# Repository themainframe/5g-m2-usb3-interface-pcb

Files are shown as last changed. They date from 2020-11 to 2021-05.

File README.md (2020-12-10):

# 5G M.2 USB3 Interface Board

I’ve been experimenting with 5G cellular modules recently, and found that many of the M.2 break-out boards that run on just USB power (mostly designed for 4G modules) can’t supply the required current at the peaks during transmission. I decided to design my own in KiCad with dual-power input, Nano-SIM slot, and USB 3 to support the required data rates for 5G. 

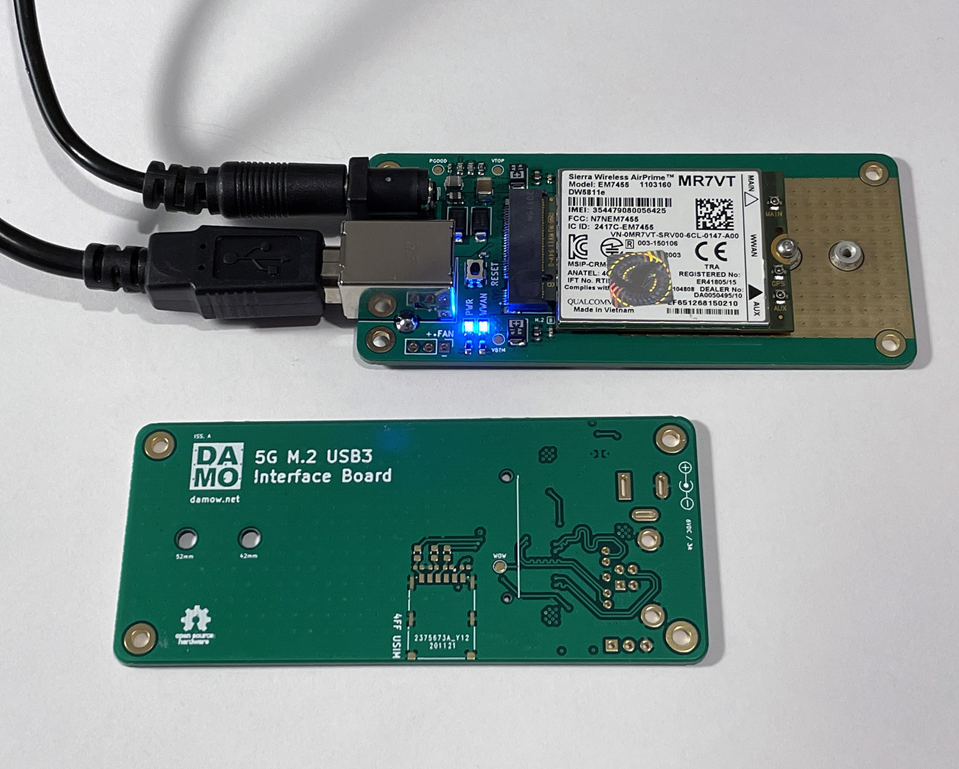
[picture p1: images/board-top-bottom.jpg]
Board with an old 4G module installed for testing. No, I don't care about the IMEI number...


I'm using mine with a Quectel [RM500Q-GL](https://www.quectel.com/product/rm500q.htm) 5G module that I've previously [blogged about](https://damow.net/5g-home-broadband/). The design very much obeys the appnote recommendations for the RM500Q-GL module so use with that one especially should work fine.

## Features

* Compact size, 90mm x 40mm board size; with 82mm x 32mm spaced M2.5 mounting holes
* USB 3.0 SuperSpeed for high 5G data rates
* Dual-power input.
    * USB 3.0 B (not recommended for heavy data use, but fine for lower-end modules)
    * 5-9V DC 5.5mm barrel jack (centre-positive)
* Fits both 52mm and 42mm M.2 B-Key modules
* Single 4FF Nano-SIM USIM slot
* Module reset button
* Module WWAN LED
* Power LED
* 5V 3-pin fan header

## Stackup & BOM

4 layers. Standard FR4. ENIG recommended for easier soldering of the fine-pitch parts (M.2 connector & TPS82130SILR DC-DC converter)

BOM can be found in the `bom/` directory. Currency is GBP. Total build cost (excluding non-special caps & resistors) is ~£15 in 10qty.

## Questions?

Open an issue or drop me an email - `me@` my blog domain.

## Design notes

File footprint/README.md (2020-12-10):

# Third Party Footprint Assets

Some of these assets are property of their respective owners.

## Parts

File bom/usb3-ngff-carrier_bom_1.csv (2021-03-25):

Component | Description | Part | References | Value | Footprint | Quantity Per PCB | Datasheet | SKU | Vendor | Int @ 10 | MPN | Mfr | Note
1 | Unpolarized capacitor | C | C8 C13 | 10pF | C_0402_1005Metric | 2 | ~ | 963-TMK042CG100DD-W | Mouser | 0.031 | TMK042CG100DD-W | Taiyo-Yuden
2 | Unpolarized capacitor | C | C7 C12 C14 C17 C18 C19 | 33pF | C_0402_1005Metric | 6 | ~ | 81-GRM0225C1H330JA2L | Mouser | 0.038 | GRM0225C1H330JA02L | MuRata Electronics
3 | Unpolarized capacitor | C | C2 | 430pF | C_0402_1005Metric | 1 | ~ | 80-C0402C431J5GACTU | Mouser | 0.206 | C0402C431J5GACTU | KEMET
4 | Unpolarized capacitor | C | C6 C11 C16 | 100nF | C_0402_1005Metric | 3 | ~ | 80-C0402C104K9RAUTO | Mouser | 0.039 | C0402C104K9RACAUTO | KEMET
5 | Unpolarized capacitor | C | C5 C10 | 1uF | C_0603_1608Metric | 2 | ~ | 80-C0603C105K9R7411 | Mouser | 0.077 | C0603C105K9RAC7411 | KEMET
6 | Unpolarized capacitor | C | C1 | 10uF | C_0805_2012Metric | 1 | ~ | 963-JMF212AB7106KGHT | Mouser | 0.106 | JMF212AB7106KGHT | Taiyo-Yuden
7 | Unpolarized capacitor | C | C3 | 22uF | C_1210_3225Metric | 1 | ~ | 963-TMK325B7226MMHP | Mouser | 0.386 | TMK325B7226MMHP | Taiyo-Yuden
8 | Polarized capacitor | CP | C4 C9 | 100uF | CP_EIA-3528-21_Kemet-B | 2 | ~ | 667-6TPE100MZB | Mouser | 0.703 | 6TPE100MZB | Panasonic | Tantalum
9 | Light emitting diode | LED | D3 D4 | LED | LED_0805_2012Metric | 2 | ~ | 604-APTD2012LQBCD | Mouser | 0.284 | APTD2012LQBC/D | Kingbright | WWAN VCCON
10 | 40V 3A Schottky Barrier Rectifier Diode, SMA(DO-214AC) | MBRA340 | D1 D2 | MBRA340 | D_SMA | 2 | https://www.onsemi.com/pub/Collateral/MBRA340T3-D.PDF | 863-MBRA340T3G | Mouser | 0.262 | MBRA340T3G | ON Semiconductor
11 | Mounting Hole without connection | MountingHole | H1 H2 | M2 Threaded Insert | 9774015243RStandoff | 2 | https://www.mouser.co.uk/datasheet/2/445/9774015243R-1728818.pdf | 710-9774015243R | Mouser | 0.785 | 9774015243R | Wurth
12 |  | 2199119-3 | J2 | 2199119-3 | TE_2199119-3 | 1 |  | 571-2199119-3 | Mouser | 0.831 | 2199119-3 | TE Connectivity | NGFF (M.2 B-Key)
13 |  | 692221030100 | J1 | 692221030100 | Wurth-692221030100-0-0-MFG | 1 | https://katalog.we-online.de/em/datasheet/692221030100.pdf | 710-692221030100 | Mouser | 2.79 | 692221030100 | Wurth
14 |  | 693043020611 | J4 | 693043020611 | Wurth-693043020611-MFG | 1 | https://www.we-online.com/catalog/datasheet/693043020611.pdf | 710-693043020611 | Mouser | 1.25 | 693043020611 | Wurth
15 | Generic connector, single row, 01x03, script generated (kicad-library-utils/schlib/autogen/connector/) | Conn_01x03_Male | J5 | Conn_01x03_Male | PinHeader_1x03_P2.54mm_Vertical | 1 | ~
16 | DC Barrel Jack with a mounting pin | Barrel_Jack_MountingPin | J3 | Jack-DC | BarrelJack_Wuerth_6941xx301002 | 1 | ~ | 710-694106301002 | Mouser | 0.74 | 694106301002 | Wurth
17 | Resistor | R | R6 R7 R8 | 22R | R_0603_1608Metric | 3 | ~
18 | Resistor | R | R1 R4 R9 | 330R | R_0603_1608Metric | 3 | ~
19 | Resistor | R | R2 R5 | 100k | R_0603_1608Metric | 2 | ~
20 | Resistor | R | R3 | 374k | R_0603_1608Metric | 1 | ~
21 |  | KMR221GLFS | SW1 | KMR221GLFS | CK-KMR221GLFS-MFG | 1 | https://www.ckswitches.com/media/1479/kmr2.pdf | 611-KMR221G-LFS | Mouser | 0.411 | KMR221GLFS | C&K
22 |  | TPS82130SILR | U1 | TPS82130SILR | Texas_Instruments-SIL0008D-0-0-0 | 1 | http://www.ti.com/lit/ds/symlink/tps82130.pdf | 595-TPS82130SILR | Mouser | 2.72 | TPS82130SILR | Texas Instruments

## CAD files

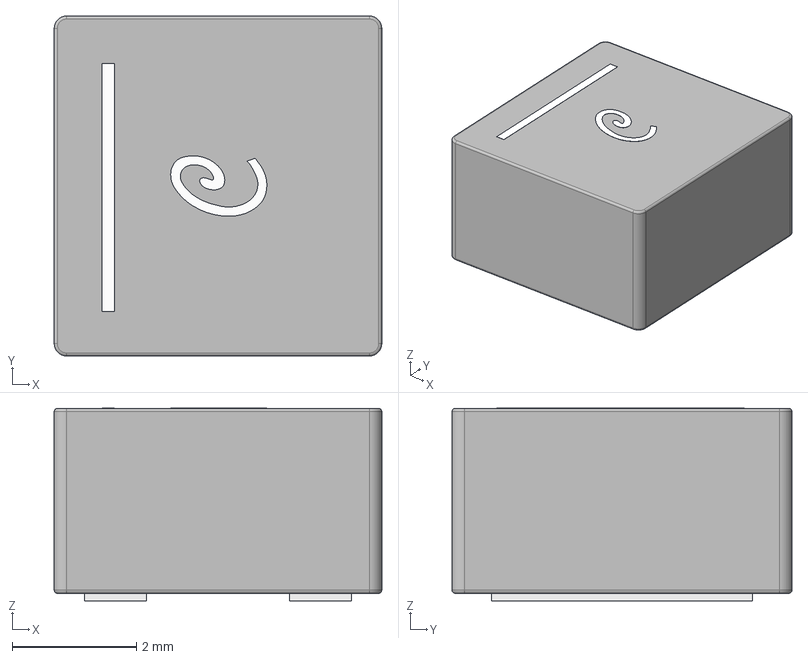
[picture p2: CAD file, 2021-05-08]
3d/Coilcraft_-_XAL5030-222MEB.step
5.28 x 5.48 x 3.10 mm
terminals
logo

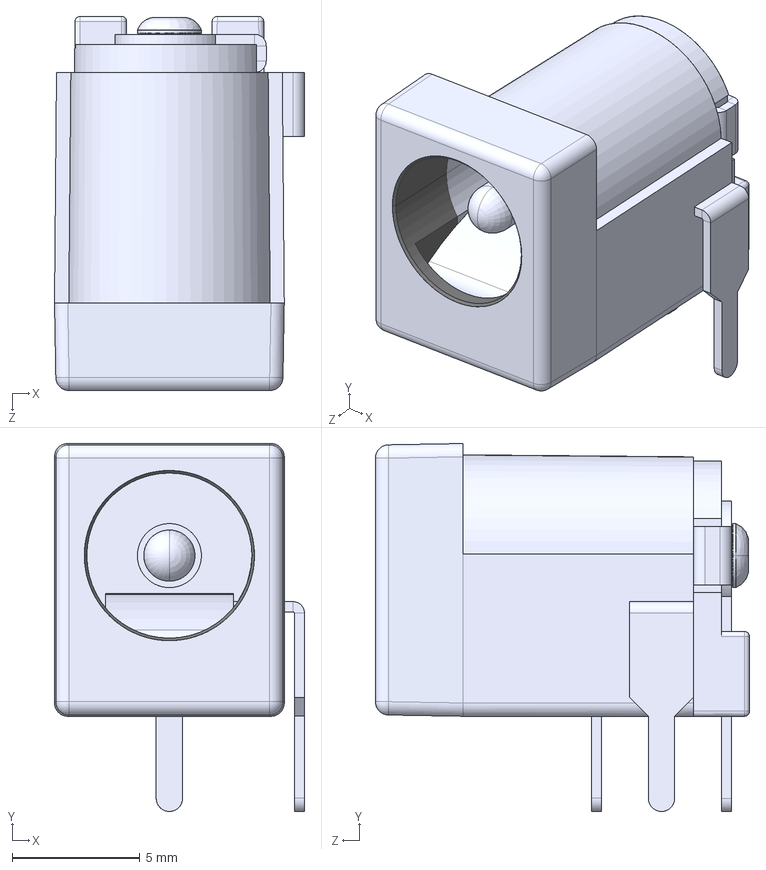
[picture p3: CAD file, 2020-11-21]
3d/DC Power Jack 5.5mm x 2.1mm.IGS
9.77 x 14.4 x 14.6 mm

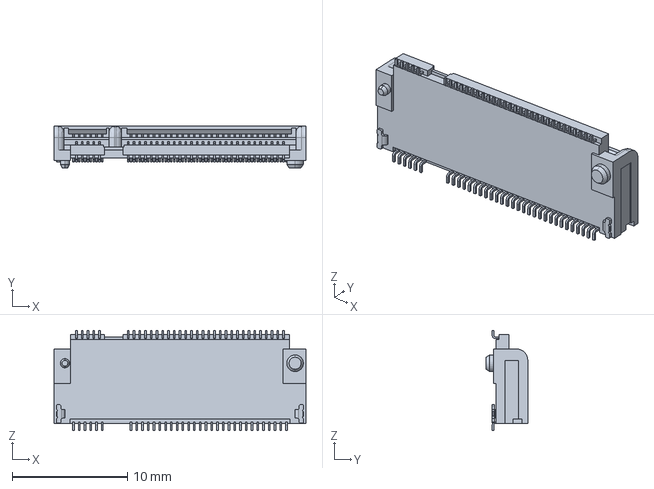
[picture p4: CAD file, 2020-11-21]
3d/c-2199119-3-c-3d.stp
21.9 x 3.62 x 8.70 mm

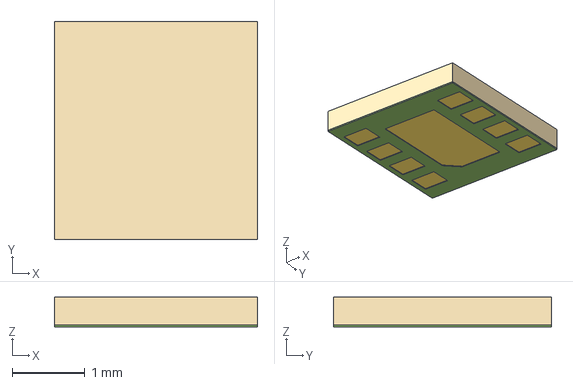
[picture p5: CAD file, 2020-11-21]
3d/Texas_Instruments_-_TPS82130SILR.step
2.80 x 3.00 x 0.41 mm

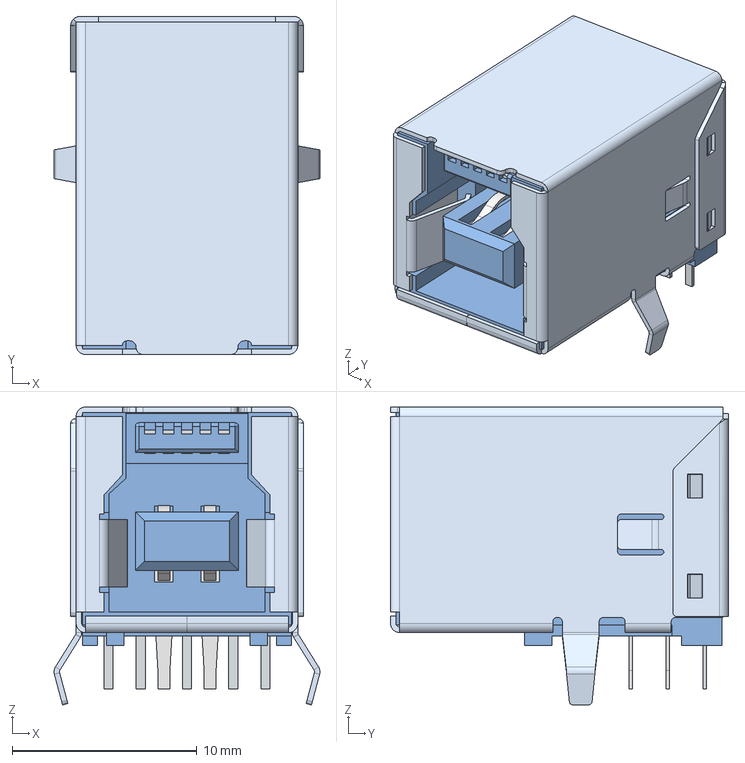
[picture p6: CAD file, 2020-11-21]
3d/Wurth_-_692221030100.step
14.4 x 18.3 x 16.1 mm

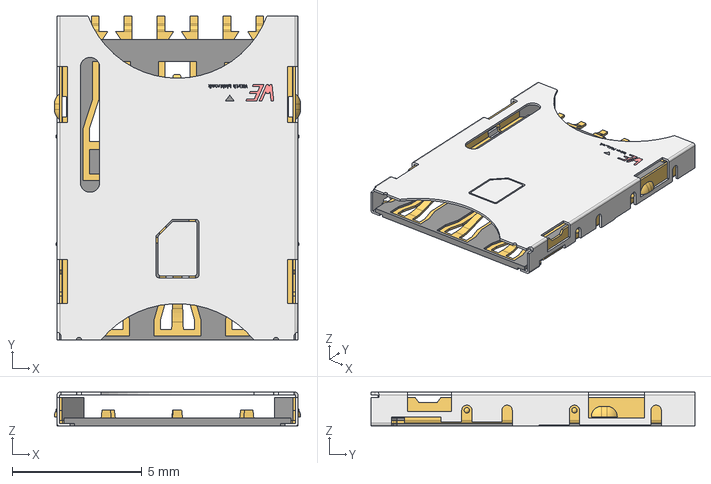
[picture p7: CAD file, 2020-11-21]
3d/Wurth_-_693043020611.step
9.50 x 12.5 x 1.30 mm

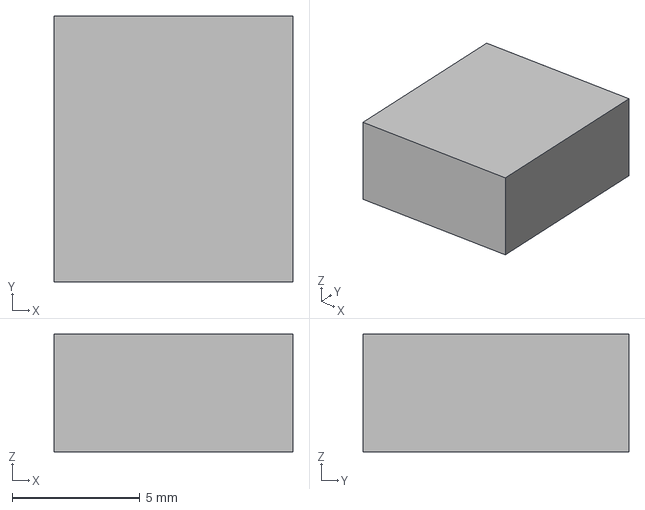
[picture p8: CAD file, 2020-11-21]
3d/STMicroelectronics_-_LD1085D2T33R.step
9.35 x 10.4 x 4.60 mm

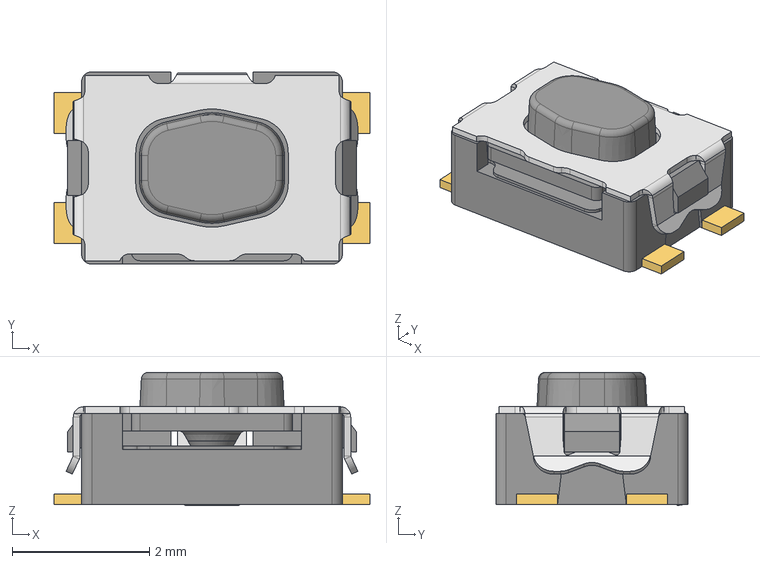
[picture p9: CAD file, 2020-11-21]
3d/C&K_-_KMR221GLFS.step
4.60 x 2.80 x 1.94 mm

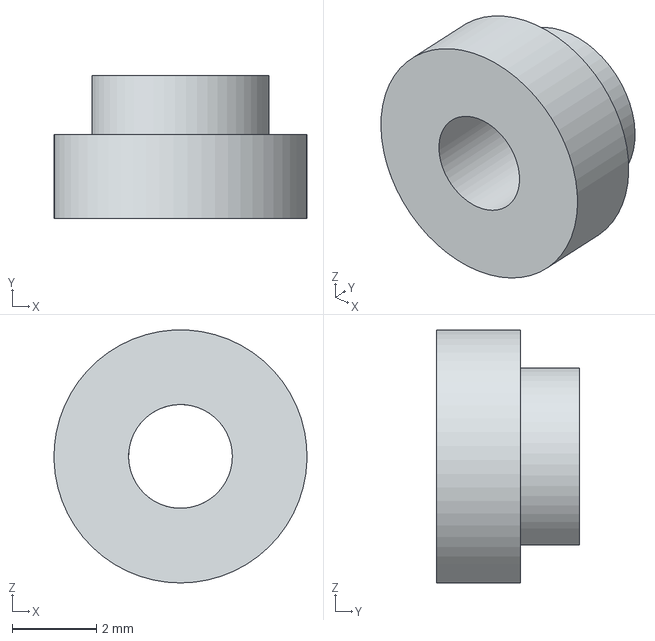
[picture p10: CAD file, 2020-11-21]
3d/9774020360R-Standoff.stp
6.00 x 3.40 x 6.00 mm

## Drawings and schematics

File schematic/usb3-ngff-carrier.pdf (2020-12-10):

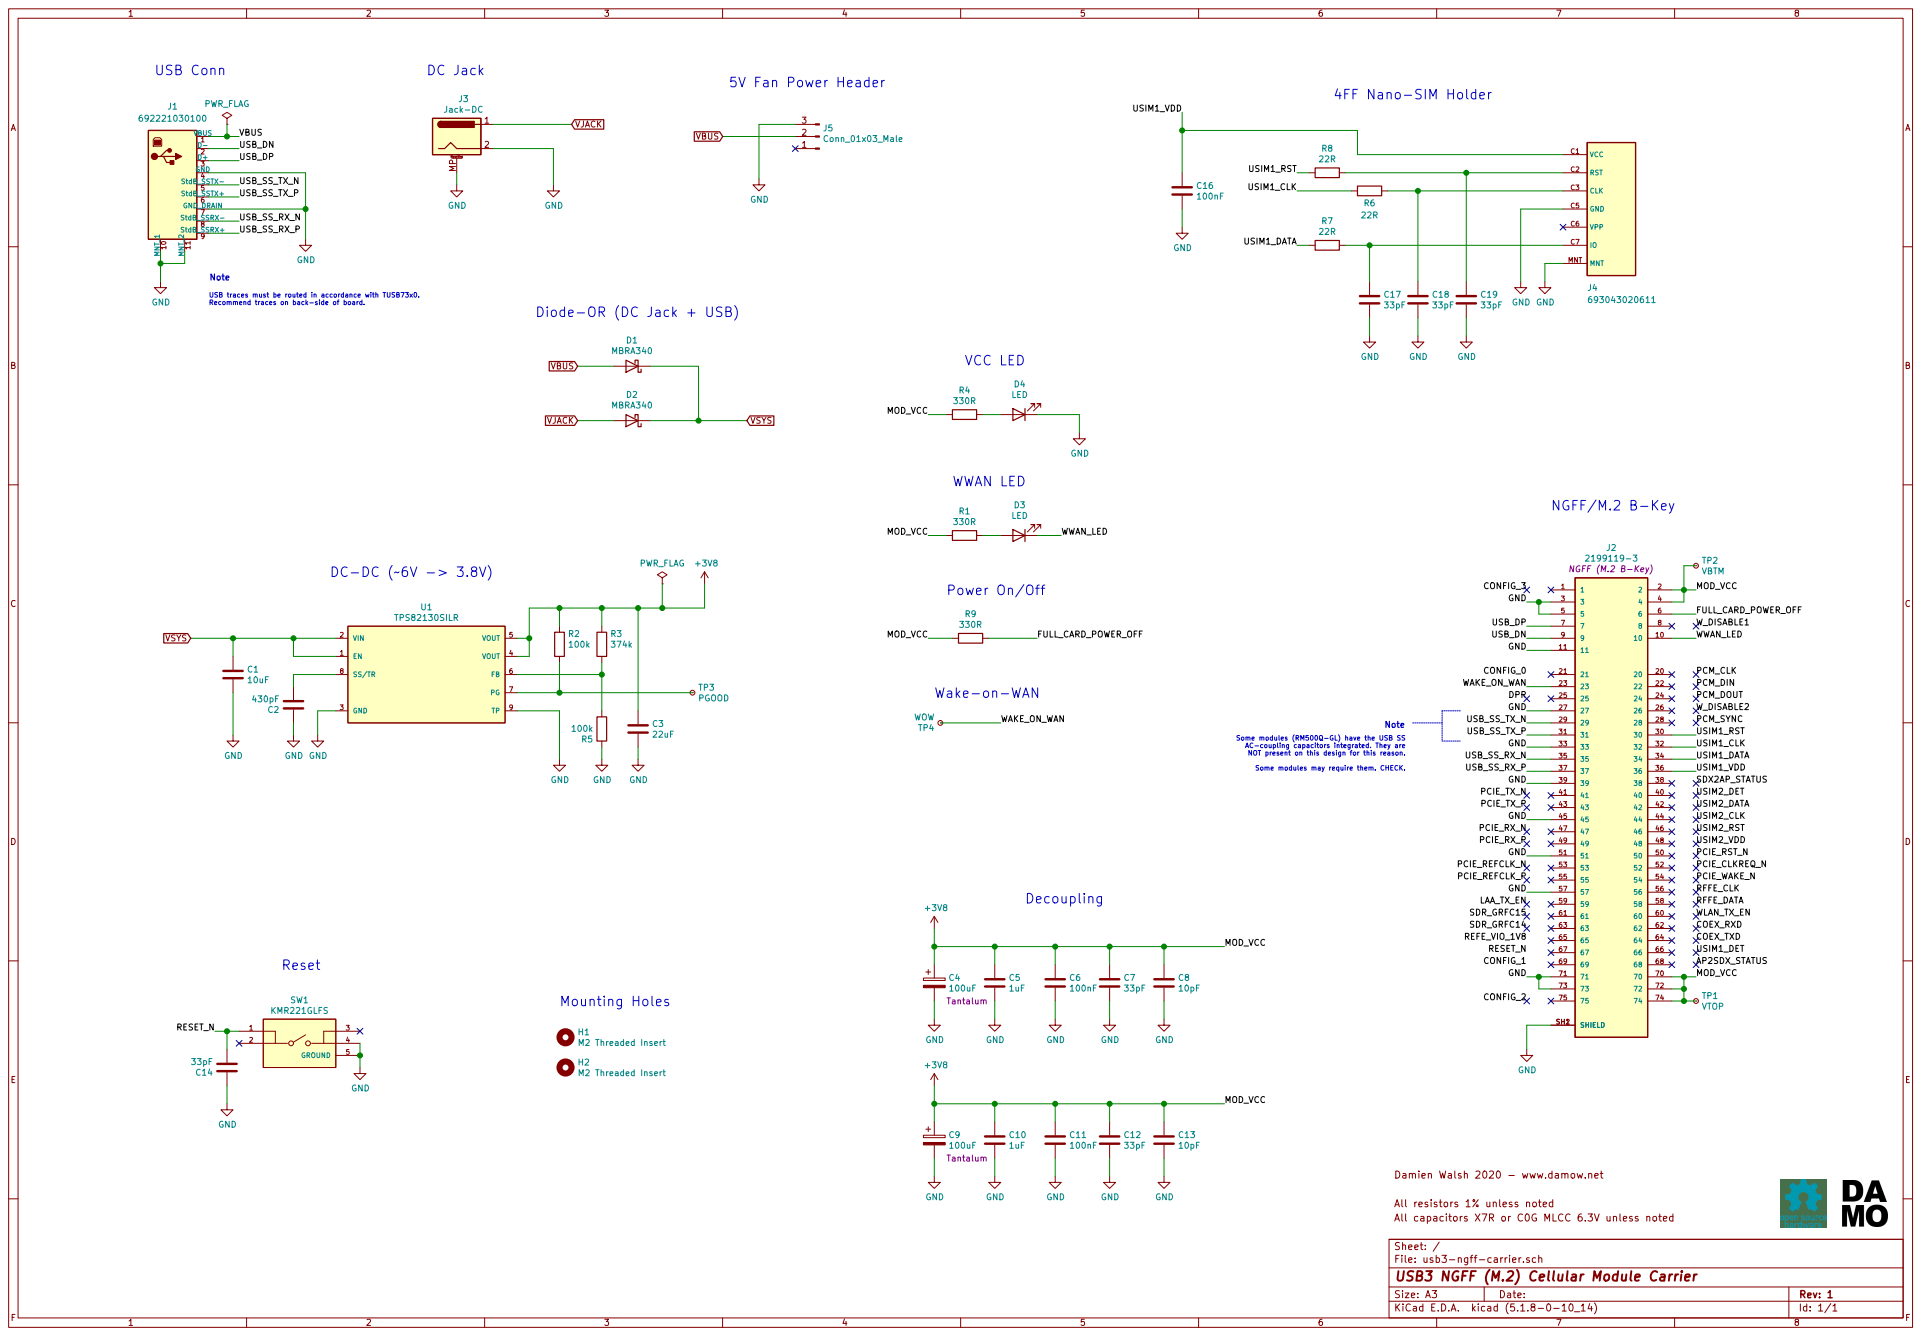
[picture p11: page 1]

SDR_GRFC14 SDR_GRFC15 Diode-OR (DC Jack + USB)

AC-coupling capacitors integrated. They are NOT present on this design for this reason. Some modules may require them. CHECK. Power On/Off

Some modules (RM500Q-GL) have the USB SS

H2M2 Threaded Insert H1M2 Threaded Insert GND

File: usb3-ngff-carrier.sch Sheet: / All capacitors X7R or C0G MLCC 6.3V unless noted All resistors 1% unless noted Damien Walsh 2020 - www.damow.net

Id: 1/1 USB3 NGFF (M.2) Cellular Module Carrier

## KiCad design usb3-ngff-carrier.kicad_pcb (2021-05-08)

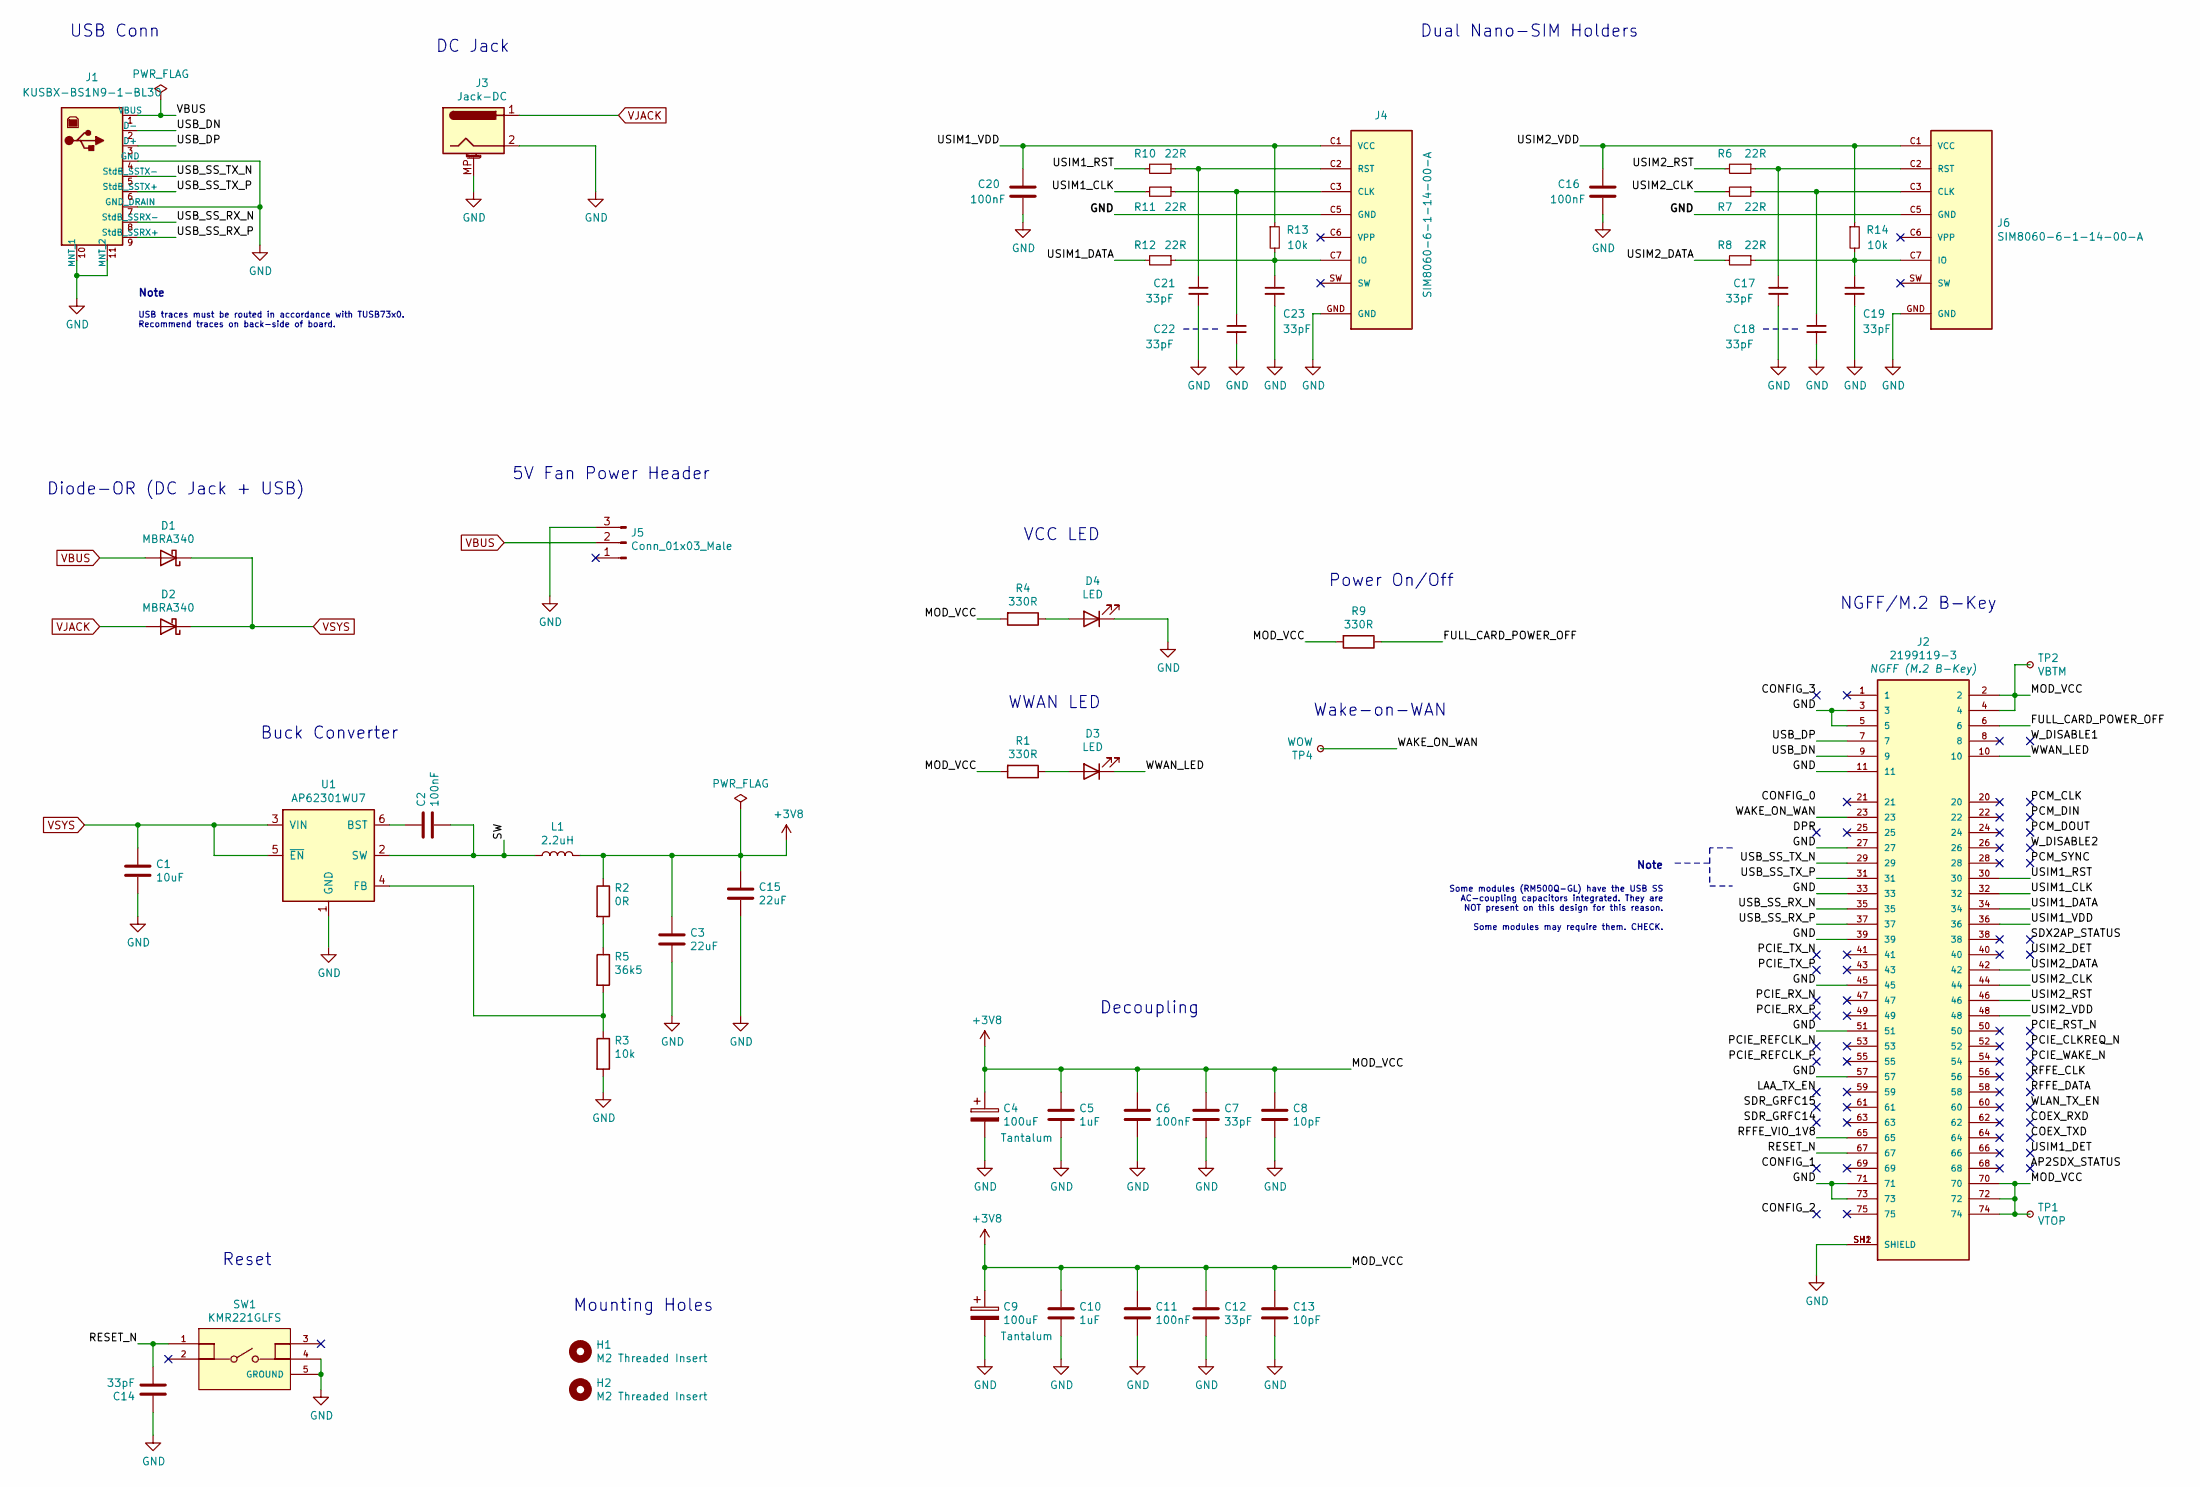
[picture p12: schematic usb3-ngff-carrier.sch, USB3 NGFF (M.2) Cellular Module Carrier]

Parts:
C1: 10uF; C_0805_2012Metric; MPN GRM21BR71A106KA73K
C2, C6, C11, C16, C20: 100nF; C_0603_1608Metric; MPN C0603C104K3RAC
C3, C15: 22uF; C_1210_3225Metric; MPN CL32B226MOJNNNE
C4, C9: 100uF; CP_EIA-3528-21_Kemet-B; MPN TCJB107M006R0040
C5, C10: 1uF; C_0603_1608Metric; MPN CGA3E1X7R1C105K080AC
C7, C12, C14, C17, C18, C19, C21, C22, C23: 33pF; C_0603_1608Metric; MPN 06035A330KAT2A
C8, C13: 10pF; C_0603_1608Metric; MPN 06035A100JAT4A
D1, D2: MBRA340; D_SMA; MPN MBRA340T3G
D3, D4: LED; LED_0805_2012Metric; MPN APTD2012LQBC/D
H1, H2: M2 Threaded Insert; 9774015243RStandoff; MPN 9774015243R
J1: KUSBX-BS1N9-1-BL30; Wurth-692221030100-0-0-MFG; MPN KUSBX-BS1N9-1-BL30
J2: 2199119-3; TE_2199119-3; MPN 2199119-3
J3: Jack-DC; BarrelJack_Wuerth_6941xx301002; MPN 694106301002
J4, J6: SIM8060-6-1-14-00-A; GCT_SIM8060-6-1-14-00-A; MPN SIM8060-6-1-14-00-A
J5: Conn_01x03_Male; PinHeader_1x03_P2.54mm_Vertical
L1: 2.2uH; L_Coilcraft_XAL5030; MPN XAL5030-222MEC
R1, R4, R9: 330R; R_0603_1608Metric
R2: 0R; R_0603_1608Metric
R3, R13, R14: 10k; R_0603_1608Metric
R5: 36k5; R_0603_1608Metric; MPN CRCW060336K5FKEA
R6, R7, R8, R10, R11, R12: 22R; R_0603_1608Metric
SW1: KMR221GLFS; CK-KMR221GLFS-MFG; MPN KMR221GLFS
TP1: VTOP; TestPoint_Pad_D1.5mm
TP2: VBTM; TestPoint_Pad_D1.5mm
TP4: WOW; TestPoint_Pad_D1.5mm
U1: AP62301WU7; TSOT-23-6; MPN AP62301WU-7

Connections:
+3V8: C3.1, C4.1, C5.1, C6.1, C7.1, C8.1, C9.1, C10.1, C11.1, C12.1, C13.1, C15.1, J2.2, J2.4, J2.70, J2.72, J2.74, L1.2, R1.2, R2.1, R4.2, R9.2, TP1.1, TP2.1
/FULL_CARD_POWER_OFF: J2.6, R9.1
/RESET_N: C14.2, J2.67, SW1.1
/RFFE_VIO_1V8: J2.65
/SW: C2.2, L1.1, U1.2 (SW)
/USB_DN: J1.2 (D-), J2.9
/USB_DP: J1.3 (D+), J2.7
/USB_SS_RX_N: J1.8 (StdB_SSRX-), J2.35
/USB_SS_RX_P: J1.9 (StdB_SSRX+), J2.37
/USB_SS_TX_N: J1.5 (StdB_SSTX-), J2.29
/USB_SS_TX_P: J1.6 (StdB_SSTX+), J2.31
/USIM1_CLK: J2.32, R11.2
/USIM1_DATA: J2.34, R12.2
/USIM1_RST: J2.30, R10.2
/USIM1_VDD: C20.1, J2.36, J4.C1 (VCC), R13.1
/USIM2_CLK: J2.44, R7.2
/USIM2_DATA: J2.42, R8.2
/USIM2_RST: J2.46, R6.2
/USIM2_VDD: C16.1, J2.48, J6.C1 (VCC), R14.1
/WAKE_ON_WAN: J2.23, TP4.1
/WWAN_LED: D3.1 (K), J2.10
GND: C1.2, C3.2, C4.2, C5.2, C6.2, C7.2, C8.2, C9.2, C10.2, C11.2, C12.2, C13.2, C14.1, C15.2, C16.2, C17.2, C18.2, C19.2, C20.2, C21.2, C22.2, C23.2, D4.1 (K), J1.4 (GND), J1.7 (GND_DRAIN), J1.10 (MNT_1), J1.11 (MNT_2), J2.3, J2.5, J2.11, J2.27, J2.33, J2.39, J2.45, J2.51, J2.57, J2.71, J2.73, J2.SH1 (SHIELD), J2.SH2 (SHIELD), J3.2, J3.MP (MountPin), J4.C5 (GND), J4.GND, J5.3, J6.C5 (GND), J6.GND, R3.2, SW1.4, SW1.5 (GROUND), U1.1 (GND)
unnamed: C2.1, U1.6 (BST)
unnamed: C17.1, J6.C2 (RST), R6.1
unnamed: C18.1, J6.C3 (CLK), R7.1
unnamed: C19.1, J6.C7 (IO), R8.1, R14.2
unnamed: C21.1, J4.C2 (RST), R10.1
unnamed: C22.1, J4.C3 (CLK), R11.1
unnamed: C23.1, J4.C7 (IO), R12.1, R13.2
unnamed: D3.2 (A), R1.1
unnamed: D4.2 (A), R4.1
unnamed: R2.2, R5.1
unnamed: R3.1, R5.2, U1.4 (FB)
VBUS: D1.2 (A), J1.1 (VBUS), J5.2
VJACK: D2.2 (A), J3.1
VSYS: C1.1, D1.1 (K), D2.1 (K), U1.3 (VIN), U1.5 (~EN)

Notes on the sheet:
Dual Nano-SIM Holders
VCC LED
WWAN LED
Reset
5V Fan Power Header
Diode-OR (DC Jack + USB)
USB Conn
DC Jack
Power On/Off
Decoupling
NGFF/M.2 B-Key
Wake-on-WAN
Mounting Holes
Note
Some modules (RM500Q-GL) have the USB SS AC-coupling capacitors integrated. They are NOT present on this design for this reason. Some modules may require them. CHECK.
USB traces must be routed in accordance with TUSB73x0. Recommend traces on back-side of board.
Buck Converter

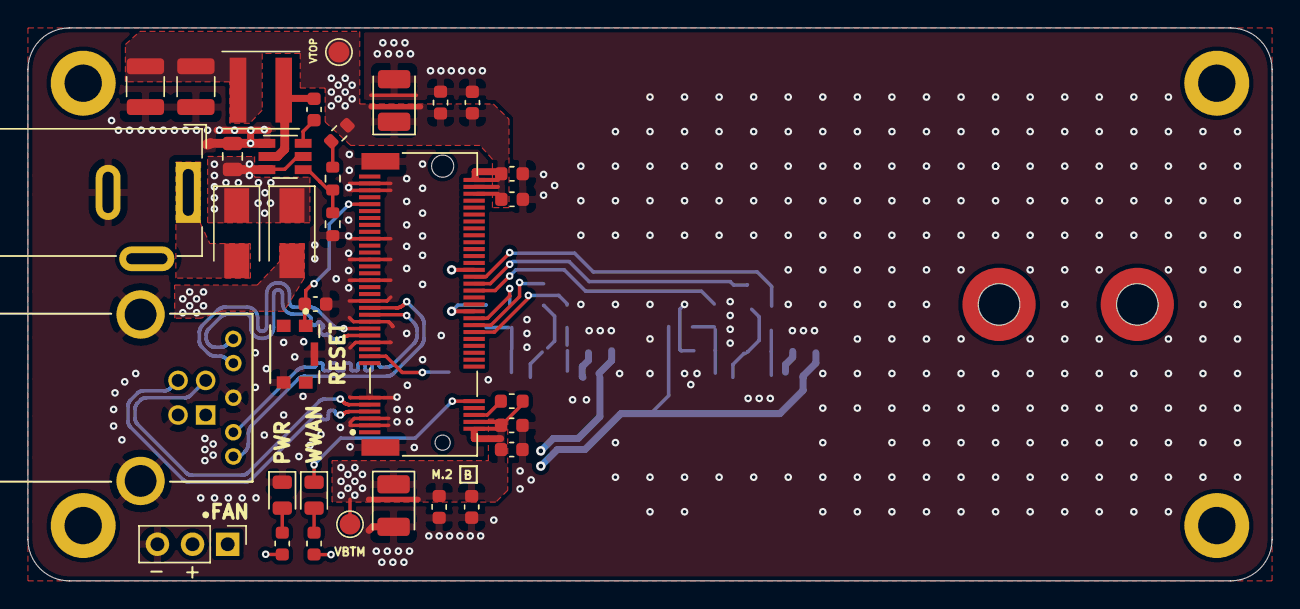
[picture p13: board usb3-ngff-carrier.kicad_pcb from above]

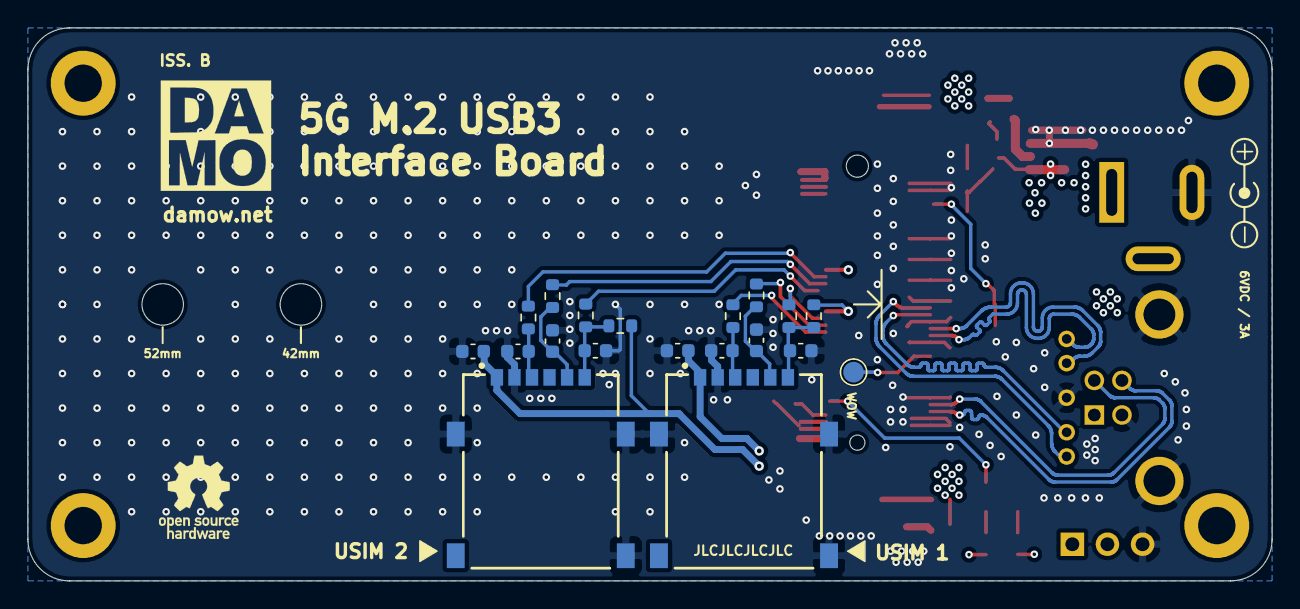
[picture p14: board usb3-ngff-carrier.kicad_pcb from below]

Board: 4 copper layers, 90.0 x 40.0 mm, 55 parts (19 on the bottom side), 35 nets.

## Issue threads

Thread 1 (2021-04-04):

Very nice design, but lacks sufficient cooling area for 5G

mlinuxguy, 2021-04-04:
I've been playing with 5G modems for my home internet and have various USB 3.0 M.2 sleds that I've tried.  Your design is one of the better ones I've seen with the extra power supply port (5G modems eat up electrons).

Because of all the heat generated by these modems there needs to be sufficient space under the M.2 connector to put a heatsink under the modem like:  icepc M.2 2280 SSD Pure Copper Heatsink Kit Cooler Heat Sink with Silicone Based Thermal Pad for Cooling M.2 SSD NGFF NVME SSD(70x20x2mm)

I suspect a taller M.2 connector would allow such a heatsink.   The WG1608 router has that along with a large copper plane on the PCB directly under the modem.  In my testing having the PCB plane + heat-sink under and on top of the modem keeps it about 5-7C cooler than just on the top of the modem.

I did some quick searches and its likely an option would be a vertical M.2 connector option.  Though bulky it would allow plenty of cooling.

themainframe, 2021-04-05:
Thanks for the feedback, glad you like the design! I'm not convinced a heatsink fitted *under* the modem (other than the interface PCB itself) is really called for though. I didn't see any implementations where the module had a heatsink fitted *underneath*. Quectel's app note for the RM500Q-GL says the following:

> Add as many ground vias as possible on PCB.
> It is NOT recommended to apply solder mask on the main PCB where the module’s thermal
dissipation area is located.

The 3 ground layers of the board are heavily stitched underneath the thermal dissipation area. The copper is exposed in this area. To improve the thermal coupling between the module and the board I've used one of these: [https://quietpc.co.uk/gelid-gp-pads](https://quietpc.co.uk/gelid-gp-pads) (I think the 2mm one). In this case, minimising the distance between the rear plane of the module and the board is desirable; the thinner pads are going to have lower thermal resistance.

> If possible, add a heatsink *on the top of the module*. In this case, A thermal pad should be used
between the heatsink and the module, and the heatsink should be designed with as many fins as possible to increase the heat dissipation area.
> Maximize airflow over/around the module.
> Use active cooling method when it is necessary to pull heat away from the module.

I found a heatsink on top of the module as advised provides good cooling. There's a 5V fan header on the board to permit active cooling too - Noctua make some nice 40mm 5V fans that work fine for this.

Other modules might work better with different cooling setups to the one Quectel describe though.

mlinuxguy, 2021-04-05:
My use case for the RM500Q-AE is outside in an enclosure powered by POE++ so Summer heat of a few weeks at 45C will push the modem's heat dissipation.  Currently is 22C outside and modem is 36C (heat-sink on top only), previously inside the WG1608 with heatsink on top and bottom it would be 32C in same conditions.

The 3 ground layers under the board will help transmit the heat.  On the current USB 3.0 adapter I have I put a copper heatsink under the PCB contacting the metal case (no metal contacts under that area to short).

We've been discussing both yours and other designs on the Openwrt ROOter forum as these 5G modems need a LOT of power under load.

I really wish my towers would get upgraded so I could see some of your throughput....  I max out at 300mbps down due to my towers.

Great design!  I may have to make one after I get this RM500Q stable... suffering from random TX hangs right now.  Got a case opened with Quectel.

themainframe, 2021-04-05:
Ah, interesting. Mine's in my fairly-cold UK loftspace with a fan and a top-mounted heatsink so I don't think I've ever seen anything above 35ºC! I should certainly consider other environments though. I think the small size of the board is also probably a detriment when it comes to heat dissipation. These big 6 & 8 layer router boards probably sink out a lot more heat than my little breakout PCB!

Off-topic - but that's fascinating about the TX dropouts! I'm actually using the RM500Q-GL on Linux with the `qmi_wwan` driver and NetworkManager and I see the same thing.  Certain applications (especially ones that open a lot of TCP connections quickly, high volume of small packets) will cause the modem to lock up. The classic symptom is the conntrack table on the machine hosting the module just gets huge and the only resolution is a USB replug/`usbreset`. Does that sound like the issue you're suffering from? I upgraded firmware to `RM500QGLABR11A02M4G` and that made no difference so I just ended up writing a Python script to `usbreset` the module if it falls over 😫

mlinuxguy, 2021-04-05:
It sounds very similar to my issues.  We now have 3 to 4 on the forum reporting the same issues with the RM500Q (AE or GL versions).   Here is a reference to my last post in the forum discussing what I was sending Quectel: https://forums.whirlpool.net.au/thread/3vx1k1r3?p=933#r18659

themainframe, 2021-04-05:
Yeah, I changed the conntrack size but it'll just get bigger and bigger as more TCP connections are attempted I think. I think the bloated conntrack size is a symptom rather than a cause. Here's what I ended up doing as a workaround: [https://gist.github.com/themainframe/d183f081dd6b8dc1eeee1b438f1754a2](https://gist.github.com/themainframe/d183f081dd6b8dc1eeee1b438f1754a2). Just added as a `systemd` service on the box hosting the module. I can check when it's restarted in the `systemd` journal then too.

It's funny because it can go days without needing a restart then have a terrible day with restarts required every few hours. I think it's just down to usage.

mlinuxguy, 2021-04-05:
Exactly what I've seen.  Some days I could run 48 hours without an issue,  get the TX hang reboot and get them constantly every 10 minutes.   Then it clears up.   So some app doing a bunch of small TCP connections seems likely.  Identifying that will be tough... I have many devices in my house along with PC's and smart phones... who knows what's doing it.

I am in an email conversation with Quectel and have provided the QLog log files that lead up to the TX hang and post hang.  It doesn't matter if you are on this rev like me:
 AT+GMR
RM500QAEAAR11A02M4G
or the A01M4G earlier rev.  All show same issue.   The US FAE for them says he hasn't seen that before....

themainframe, 2021-04-05:
Opening Blizzard's Battle.net app was almost always a sure-fire way to kill it in my experience. That's renowned for opening a million connections for their P2P patch downloading stuff.

git6578, 2021-04-25:
Wild idea, what about immersion cooling the module with electrocool EC-120?

mlinuxguy, 2021-04-25:
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
That would probably work, but I'm all about fire-and-forget (i.e. outside and don't have to mess with it so all passive).

On the RM500Q-AE TX hang front I have some info from Quectel R&D.
They see no PDN IPV6 or IPV4 request in the decoded packets at the time of hang.  They asked me what the default T-mobile needs (IPV6),  I'm not sure what PDN "Themainframe" guy needs on his.   Haven't heard back if new firmware is in the future.

mlinuxguy, 2021-11-24:
I switched out to a 8gb RPI 4 running Rooter / GoldenOrb on 21.01 RC3 of
Openwrt and that solved all the problems with USB xmit / recv storms (newer
kernel?).  The errors I got were: xhci-mtk 1e1c0000.xhci: ERROR unknown
event type 37
My setup is outside under the eve of my roof in 2 outdoor enclosures:
RM500Q-AE in its carrier plus a giant ALU heatsink under it, a short USB
3.0 cable over to the other enclosure where the RPI is bolted to its giant
heatsink.  Survived outdoor temps of 45C just fine.

I really like the Rooter/Goldenorb software for the RPI 4 as it allows me
to configure an auto-reboot of the modem when it loses internet
connection.  It's pretty much setup and forget about it now, just every
once in a while during normal hours T-mobile does something to the tower
and it reboots (and I check the routers webpage to see what happened).

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

Closed 2022-05-18.

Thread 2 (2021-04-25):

available to buy?

git6578, 2021-04-25:
Hey, your blog posts about 5g are very exciting! :)

Can I buy one of these adapters? I think you wrote you had to purchase 10 of them. Or how does this pcb manufacturing work?

I want to upgrade to 5g too, currently using a x86 ROOter but I am not convinced about my available ports (Zbox ci323). I use a 4x4 mimo Poynting 4g/5g omni antenna, probably the best part of my setup.

Do you think it makes sense to build a 5g and wifi 6e router to finally break 1gbit on endpoints? ROOter actually has poor wifi card support. And I think stability and latency is most important. How would you do it?

git6578, 2021-06-07:
dm resolved

Closed 2021-06-07.

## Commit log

2020-11-21 Change: SIM holder
    [usb3-ngff-carrier.kicad_pcb, usb3-ngff-carrier.sch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]
2020-12-10 Add: README, BOM and a few other bits
    [usb3-ngff-carrier.sch]
2020-12-10 Add: Force-add schematic & gerber PDFs
2021-03-25 Add: BOM
    [usb3-ngff-carrier_bom_1.csv]
2021-05-08 Add: Rev2 changes
    * Changed switcher to Diodes Inc device.
    * Added second USIM slot and changed USIM slot part.
    [Coilcraft_-_XAL5030-222MEB.step, usb3-ngff-carrier.kicad_pcb, usb3-ngff-carrier.sch]
2021-05-08 Add: Issue B changes finalised
    [usb3-ngff-carrier-B_Mask.gbr, usb3-ngff-carrier-B_Paste.gbr, usb3-ngff-carrier-B_SilkS.gbr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]
